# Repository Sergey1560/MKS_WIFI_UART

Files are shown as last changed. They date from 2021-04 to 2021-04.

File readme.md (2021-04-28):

# Модуль для подключения к UART плат Robin Nano

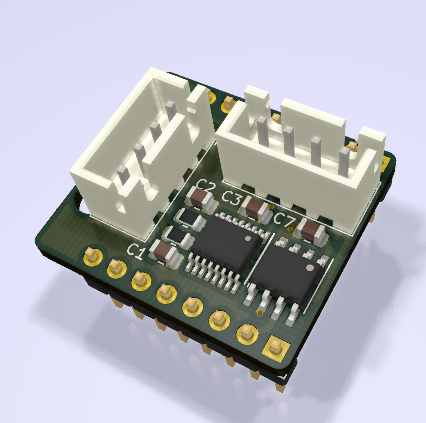
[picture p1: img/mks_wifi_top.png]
Top

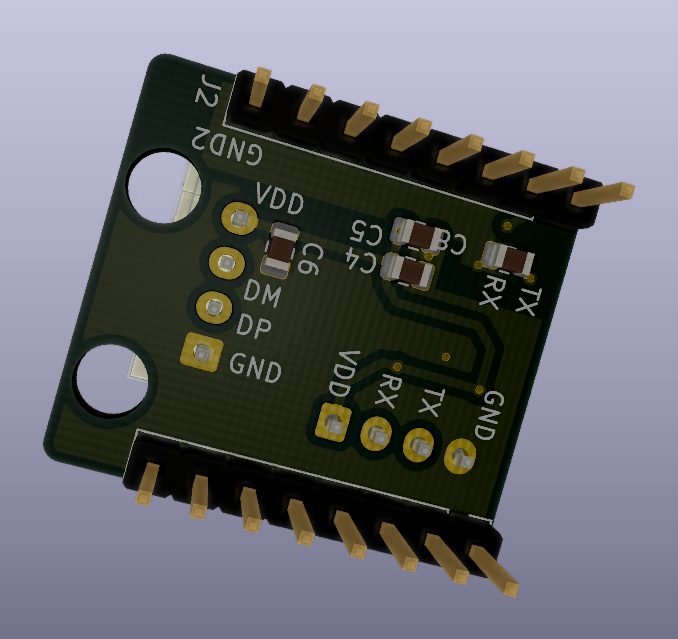
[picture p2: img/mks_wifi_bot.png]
Bottom


Данный модуль предназначен для использования с платами MKS Robin Nano. Вставляется вместо MKS WIFI модуля и позволяет подключиться по UART. На модуле установлен изолятор ISO 7712 и USB-UART преобразователь FT230. На разъем J3 выведены сигналы USB, на разъем J4 выведены сигналы UART.

Проект сделан в KiCad.

## Схема платы

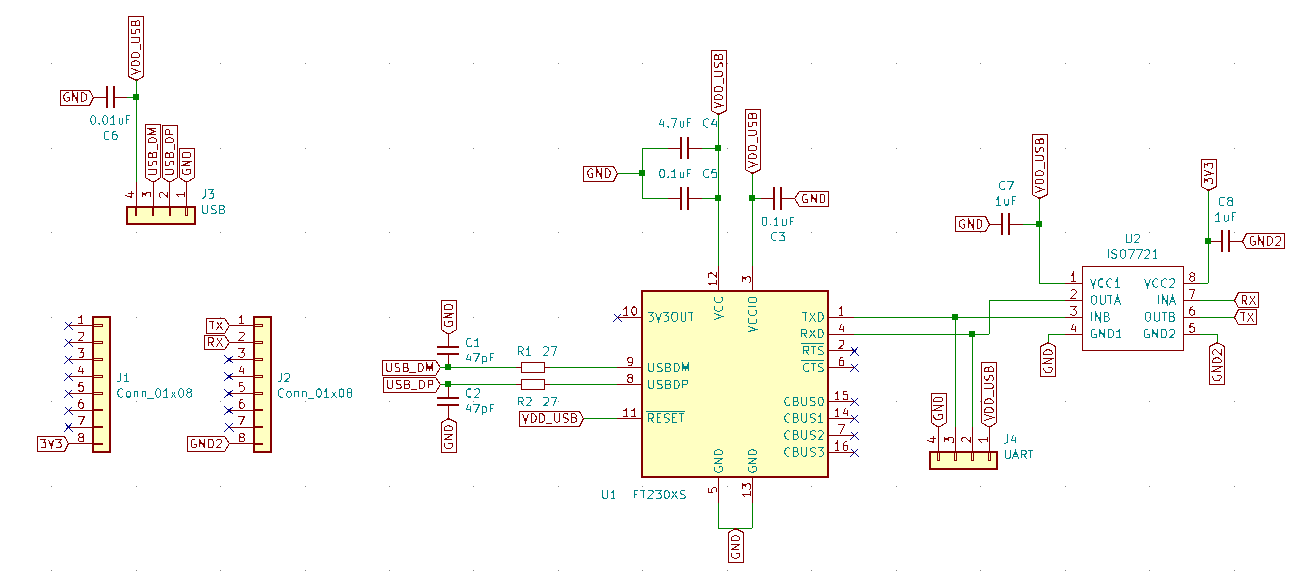
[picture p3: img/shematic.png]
Схема


## Архив с gerber файлами

[mks_wifi.zip](./gerber/mks_wifi.zip)

## Список компонентов

Список компонентов - [mks_wifi_bom.ods](./bom/mks_wifi_bom.ods)

| N  | Кол-во | Номинал | Размер | Link
| ---| --- |---|--- |----- |
| C1, C2 | 2 | 47pF | 0805 | [LCSC](https://lcsc.com/product-detail/Multilayer-Ceramic-Capacitors-MLCC-SMD-SMT_YAGEO-CC0805JRNPO9BN470_C107118.html) [TERRA](https://spb.terraelectronica.ru/product/600072) |
| C3, C5 | 2 | 0.1uF | 0805 | [LCSC](https://lcsc.com/product-detail/Multilayer-Ceramic-Capacitors-MLCC-SMD-SMT_YAGEO-CC0805KRX7R9BB104_C49678.html) [TERRA](https://spb.terraelectronica.ru/product/251110) |
| C4 | 1 | 4.7uF | 0805 | [LCSC](https://lcsc.com/product-detail/Multilayer-Ceramic-Capacitors-MLCC-SMD-SMT_Murata-Electronics-GRM21BR61C475KA88L_C97915.html) [TERRA](https://spb.terraelectronica.ru/product/234492) |
| C6 | 1 | 0.01uF | 0805 | [LCSC](https://lcsc.com/product-detail/Multilayer-Ceramic-Capacitors-MLCC-SMD-SMT_YAGEO-CC0805KRX7R9BB103_C83170.html) [TERRA](https://spb.terraelectronica.ru/product/1350309) |
| C7, C8 | 2 | 1uF | 0805 | [LCSC](https://lcsc.com/product-detail/Multilayer-Ceramic-Capacitors-MLCC-SMD-SMT_Murata-Electronics-GCM21BR71H105KA03L_C126592.html) [TERRA](https://spb.terraelectronica.ru/product/884481) |
| J1, J2 | 2 | 1uF | Conn_01x08 | [LCSC](https://lcsc.com/product-detail/Pin-Header-Female-Header_Ckmtw-Shenzhen-Cankemeng-Headers-Pins-1-8P-2-54mm-Straight-line_C124381.html) |
| J3, J4 | 2 | JST XH2.54 |  .  |
| R1, R2 | 2 | 27 Ом | 0805 | [LCSC](https://lcsc.com/product-detail/Chip-Resistor-Surface-Mount_UNI-ROYAL-Uniroyal-Elec-0805W8F270JT5E_C17594.html) [TERRA](https://spb.terraelectronica.ru/product/871706) |
| U1 | 1 | FT230XS | SSOP-16 3.9x4.9mm P0.635mm | [LCSC](https://lcsc.com/product-detail/USB-ICs_FTDI-FT230XS-R_C69082.html) [TERRA](https://spb.terraelectronica.ru/product/1339655) |
| U2 | 1 | ISO7721 | SOIC-8 3.9x4.9mm P1.27mm | [LCSC](https://lcsc.com/product-detail/Digital-Isolators_Texas-Instruments-Texas-Instruments-ISO7721DR_C366164.html) [TERRA](https://spb.terraelectronica.ru/product/2301597) |

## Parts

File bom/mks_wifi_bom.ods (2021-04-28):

Component Count: | 15 |  |  |  | LCSC |  |  | Terra
Ref | Qnty | Value | Footprint | Description | Price x1 | Price x5 | Link | Price x1 | Price x5 | Link
C1, C2, | 2 | 47pF | SMD:0805 | Unpolarized capacitor | 30 | 30 | https://lcsc.com/product-detail/Multilayer-Ceramic-Capacitors-MLCC-SMD-SMT_YAGEO-CC0805JRNPO9BN470_C107118.html | 1,04 | 5,2 | https://spb.terraelectronica.ru/product/600072
C3, C5, | 2 | 0.1uF | SMD:0805 | Unpolarized capacitor | 26 | 26 | https://lcsc.com/product-detail/Multilayer-Ceramic-Capacitors-MLCC-SMD-SMT_YAGEO-CC0805KRX7R9BB104_C49678.html | 1,34 | 6,7 | https://spb.terraelectronica.ru/product/251110
C4, | 1 | 4.7uF | SMD:0805 | Unpolarized capacitor | 49 | 49 | https://lcsc.com/product-detail/Multilayer-Ceramic-Capacitors-MLCC-SMD-SMT_Murata-Electronics-GRM21BR61C475KA88L_C97915.html | 1,6 | 8 | https://spb.terraelectronica.ru/product/234492
C6, | 1 | 0.01uF | SMD:0805 | Unpolarized capacitor | 24 | 24 | https://lcsc.com/product-detail/Multilayer-Ceramic-Capacitors-MLCC-SMD-SMT_YAGEO-CC0805KRX7R9BB103_C83170.html | 1,1 | 5,5 | https://spb.terraelectronica.ru/product/884481
C7, C8, | 2 | 1uF | SMD:0805 | Unpolarized capacitor | 48 | 48 | https://lcsc.com/product-detail/Multilayer-Ceramic-Capacitors-MLCC-SMD-SMT_Murata-Electronics-GCM21BR71H105KA03L_C126592.html | 9 | 45 | https://spb.terraelectronica.ru/product/1350309
J1, J2, | 2 | Conn_01x08 | PinHeader_2.54mm | Generic connector | 38 | 38 | https://lcsc.com/product-detail/Pin-Header-Female-Header_Ckmtw-Shenzhen-Cankemeng-Headers-Pins-1-8P-2-54mm-Straight-line_C124381.html | 0 | 0
J3, | 1 | USB | PinHeader_2.54mm | Generic connector | 0 | 0 |  | 0 | 0
R1, R2, | 2 | 27 | SMD:0805 | Resistor | 25 | 25 | https://lcsc.com/product-detail/Chip-Resistor-Surface-Mount_UNI-ROYAL-Uniroyal-Elec-0805W8F270JT5E_C17594.html | 0,36 | 1,8 | https://spb.terraelectronica.ru/product/871706
U1, | 1 | FT230XS | SSOP-16_3.9x4.9mm_P0.635mm | Full Speed USB to Basic UART, SSOP-16 | 228 | 1140 | https://lcsc.com/product-detail/USB-ICs_FTDI-FT230XS-R_C69082.html | 212 | 1040 | https://spb.terraelectronica.ru/product/1339655
U2, | 1 | ISO7721 | SOIC-8_3.9x4.9mm_P1.27mm | Digital Isolator | 95 | 475 | https://lcsc.com/product-detail/Digital-Isolators_Texas-Instruments-Texas-Instruments-ISO7721DR_C366164.html | 127,77 | 445 | https://spb.terraelectronica.ru/product/2301597
 |  |  |  |  | 563 | 1855 |  | 354,21 | 1557,2

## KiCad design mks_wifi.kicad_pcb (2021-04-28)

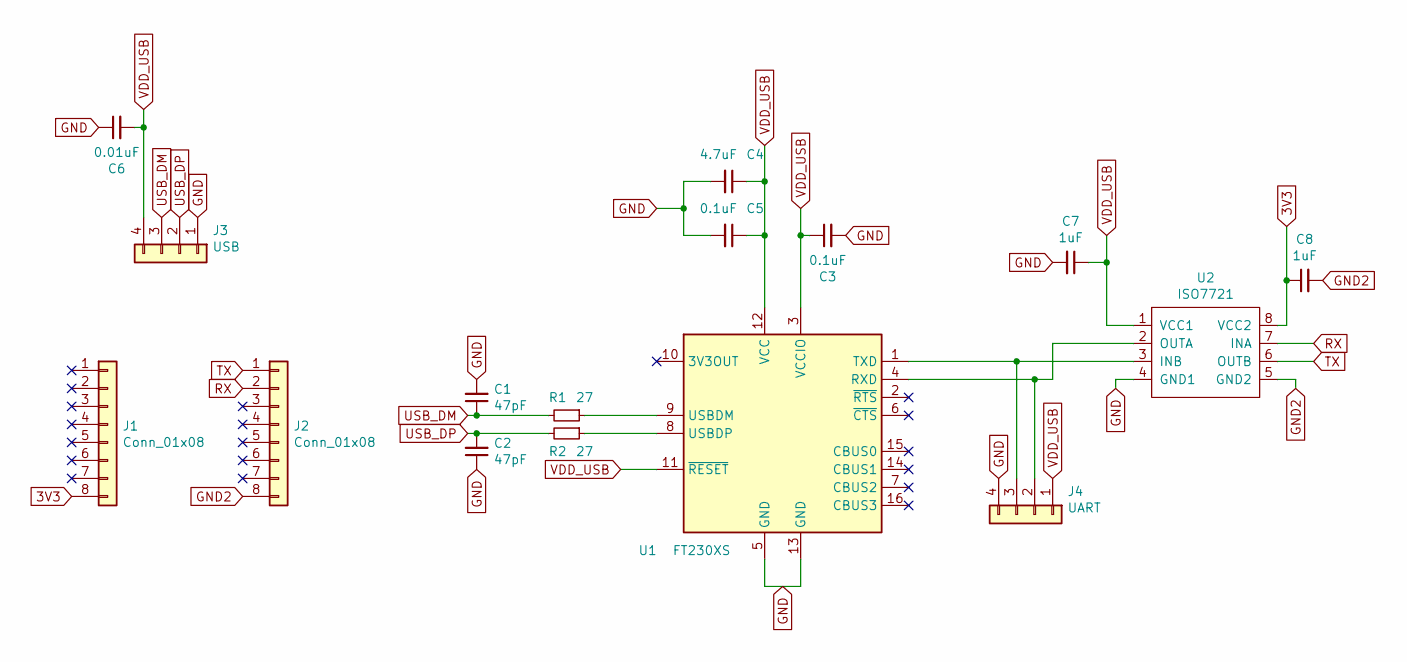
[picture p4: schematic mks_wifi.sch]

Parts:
C1, C2: 47pF; C_0805_2012Metric
C3, C5: 0.1uF; C_0805_2012Metric
C4: 4.7uF; C_0805_2012Metric
C6: 0.01uF; C_0805_2012Metric
C7, C8: 1uF; C_0805_2012Metric
J1, J2: Conn_01x08; PinHeader_1x08_P2.54mm_Vertical
J3: USB; JST_XH_B4B-XH-A_1x04_P2.50mm_Vertical
J4: UART; JST_XH_B4B-XH-A_1x04_P2.50mm_Vertical
R1, R2: 27; R_0805_2012Metric
U1: FT230XS; SSOP-16_3.9x4.9mm_P0.635mm
U2: ISO7721; SOIC-8_3.9x4.9mm_P1.27mm

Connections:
3V3: C8.1, J1.8, U2.8 (VCC2)
GND: C1.2, C2.1, C3.2, C4.2, C5.2, C6.1, C7.2, J3.1, J4.4, U1.5 (GND), U1.13 (GND), U2.4 (GND1)
GND2: C8.2, J2.8, U2.5 (GND2)
unnamed: J4.2, U1.4 (RXD), U2.2 (OUTA)
unnamed: J4.3, U1.1 (TXD), U2.3 (INB)
unnamed: R1.1, U1.9 (USBDM)
unnamed: R2.1, U1.8 (USBDP)
RX: J2.2, U2.7 (INA)
TX: J2.1, U2.6 (OUTB)
USB_DM: C1.1, J3.3, R1.2
USB_DP: C2.2, J3.2, R2.2
VDD_USB: C3.1, C4.1, C5.1, C6.2, C7.1, J3.4, J4.1, U1.3 (VCCIO), U1.11 (~RESET), U1.12 (VCC), U2.1 (VCC1)

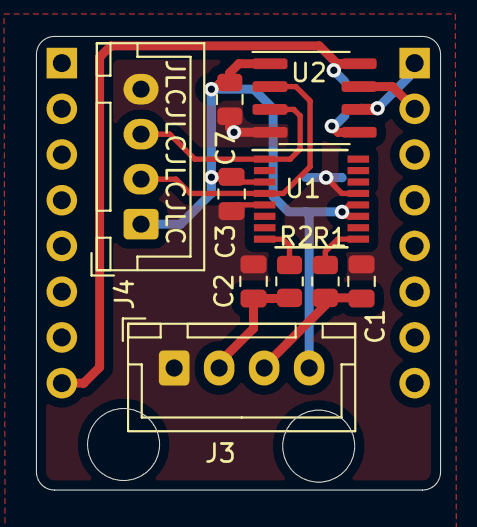
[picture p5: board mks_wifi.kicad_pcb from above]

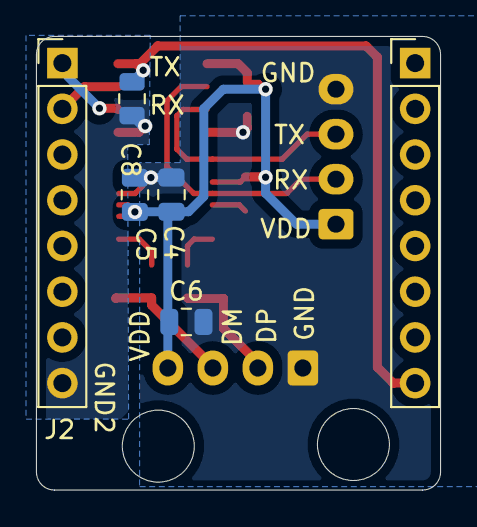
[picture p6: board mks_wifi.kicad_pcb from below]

Board: 2 copper layers, 22.5 x 25.2 mm, 16 parts (6 on the bottom side), 12 nets.

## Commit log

2021-04-28 v1, проверенный вариант
    [mks_wifi.kicad_pcb, mks_wifi.sch, mks_wifi_bom.ods]
2021-04-28 Readme, bom list
    [mks_wifi_bom.ods]
